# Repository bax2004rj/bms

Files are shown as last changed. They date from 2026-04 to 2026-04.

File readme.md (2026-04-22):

# 3S LIPO battery BMS board
This is a project that allows you to monitor the voltage of a LIPO battery arranged in a 3S configuration. It features auto switch-off by way of MOSFETs, some current monitoring capabilities, and communication with a computer using a UART. This project was designed for use with a [GooseBot](https://github.com/lznfjv/goose). The system is controlled using an Arduino Nano.
## Features
- State of Charge monitoring
- UART/Serial computer communication
- Support for current monitoring with current shunt
- Automatic shutoff on dead battery

Watch the demo video [here](https://github.com/bax2004rj/bms/raw/refs/heads/main/demos/bmsDemo.mp4).
## Installation and building
### Building hardware
Replicate the design shown in the schematics in the /pcb/ folder. PCB designs may become available at a later date.
### Building Firmware
#### Windows
- Download the Arduino IDE to help locate your Arduino, using the Board selector menu.
- Find your copy of `avrdude` (you will need this to upload this code to the Arduino). This is typically found as part of the Arduino IDE, usually under the path `C:\Users\<your username>\AppData\Local\Arduino15\packages\arduino\tools\avrdude\8.0.0-arduino1\bin\avrdude.exe`.
- Clone or download this Git repository.
- In terminal, go to the `firmware/` folder where the code was downloaded to, by running the following command:
```powershell
cd <path/to/file>
```
- Run the following command to upload it to the Arduino (bms.c has already been compiled), replacing the `path\to\board` with the location of your copy of `avrdude`, and the `<location of board>` with your Arduino's serial port:
```powershell
C:\path\to\avrdude.exe -c arduino -p m328p -P <location of board> -U flash:w:build/main.hex
```
#### Linux & MacOS
##### Prerequisites
You will need `avr-gcc` and `avrdude` to get this working.
On Ubuntu/Debian, run:
```bash
$ sudo apt install avr-gcc avrdude
```
if you don't have these tools.
##### Build Instructions
- Clone this project off Github:
```bash
$ git clone github.com/bax2004rj/bms
```
- Go to the Firmware folder under where the repo copied to:
```bash
$ cd ~/bms/firmware
```
- Provided you are not running the other demos found in `/firmware/` the code (`bms.c`) should already be built, and ready to upload to the Arduino. Plug in your Arduino, and locate it using:
```bash
$ ls /dev/ | grep tty
```
- For most Arduinos, the USB connection is typically located at `/dev/ttyACM*` where `*` is the device number. Some Nano boards, such as those used in testing with the CH340 serial driver are located at `/dev/ttyUSB*`.
>[!NOTE]
>You can also use the Arduino IDE for this task as well.

- Run the following command to upload the firmware to the board:
```bash
$ avrdude -c arduino -p m328p -P <location of board> -U flash:w:build/main.hex
```
>[!TIP]
>To compile the demos or recompile the main code (bms.c), use the following command:
>```bash
>$ avr-gcc <filename.c> -o build/main -mmcu=atmega328p -O1 $flags
>```
>Then rerun the avrdude command to upload it to the board.

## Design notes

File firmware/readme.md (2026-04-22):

# Firmware code for BMS
This directory contains the source code and binaries for the Arduino used on the BMS project. There are some demos used during development to test the included header files. These can be compiled and put on the Arduino.
These files are as follows:
- `7sd_trail0test.c`: Simple program that cycles through various numbers that may show up incorrectly on the seven segment display if `7sd.h`'s leading zero detection is faulty.
- `7sd_counttest.c`: Counts from 0-200 using the seven segment display.
- `7sd_uart_counttest`: Version of `7sd_counttest.c` that prints the expected number over the serial port.
- `bms_uart+.c`: Version of `bms.c` that contains a failed, but more advanced serial interaction system. Not recommended to evaluate the hardware.

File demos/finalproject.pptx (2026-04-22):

## Goosebot BMS Board

Richard Carter
4/21/2026

## Introduction

- Battery Management systems are used to control power delivered by battery-powered devices
- Goosebots do not presently have such circuitry
- The design shown here aims to provide this circuit.

## Materials

Item | Quantity
Arduino Nano | 1
Buck Converter | 1
MOSFET (IRF3205) | 2
7 Segment Display | 1
Opamp (LM358) | 1
Resistor (1Ω) | 1
Resistors (220Ω) | 3
Resistor (1KΩ) | 1
Resistor (2KΩ) | 1

## Design

- Design powered by Arduino Nano
- Voltage measured by voltage divider
- 7 segment display to communicate state of charge

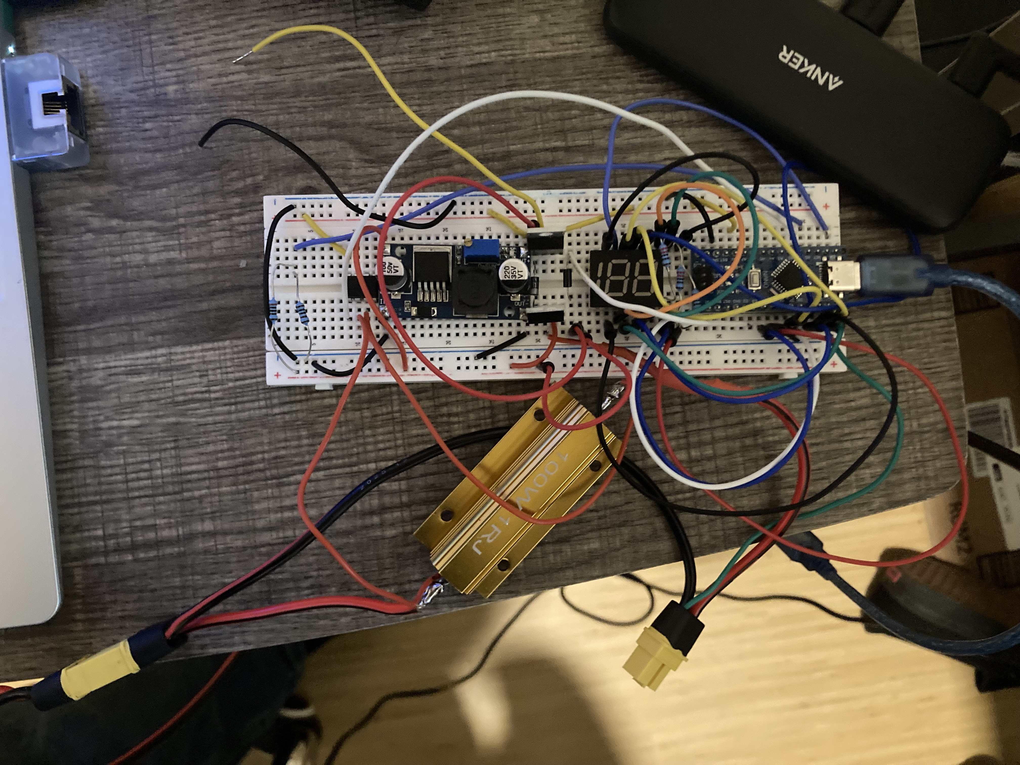
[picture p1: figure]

## Testing Method

- To simulate batteries, a DC supply was connected to the input
  - Testing on actual Goosebots could not be done in time
- Voltage was varied from 13V to 9V
- Switching behavior, state of charge display and Arduino serial ports were monitored.

## Testing

Input Voltage (V) | Arduino Reported Voltage (V) | Reported State of Charge (%)
9.95 | 9.60 | 0
11.6 | 11.2 | 49
13.0 | 13.13 | 100

- Core functionality (voltage measurement) worked largely as expected
- Automatic shut-off did not work, MOSFETS were not properly switched.
- Future iterations may need a MOSFET gate driver.

State Of Charge vs. Voltage

Input Voltage (V) | Output Voltage (V) | Arduino pin voltage (V)
11.5 | 7.936 | 4.835
9.88 | 8.339 | 0.98

Automatic shut-off behavior

## Conclusion

- Voltage monitoring and computer communication was successfully achieved
- Some elements were not functional
  - Current monitoring not fully built in software
  - Battery shutoff functionality was not working

## Thank you!

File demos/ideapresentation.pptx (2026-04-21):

## Goosebot BMS Board Idea

Richard Carter
EEL4312, 4/15/2026

## Design requirements

- 7-Segment display battery level indicator
- Automatic shutoff when battery voltage too low
- UART connection with SBC for communication
- Built in buck converter to run SBC

## Materials and method

- Powered by Arduino Nano
- Sense current using current shunt and voltage divider to measure voltage
- MOSFETs used to switch 12V and 5V rails off

Arduino Nano

D3-13

TX&RX

Display

SBC UART

A0

D2

5V

Buck
converter

Battery

Op-amp

Current Shunt

Gate

5V shut off

5V

Outputs

12V
MOSFET
shut-off

12V

Circuit Block Diagram

## Materials and Method, continued (BOM)

Item | Quantity
Arduino Nano | 1
Buck Converter | 1
MOSFET (IRF3205) | 2
7 Segment Display | 1
Opamp (LM358) | 1
Resistor (1Ω) | 1
Resistors (220Ω) | 3
Resistors (Values TBD) | 2

## Testing Method

- The circuit will be tested on a Goosebot
- The battery will go from fully charged to dead
  - Demonstrates automatic shut-off behavior
- UART communications will be tested during this time

## Timeline

4/9/26
Specifications and
design ideation

4/15/26
Completion of
firware design

4/16/26
Design testing

4/13/26
Parts ordering

4/15/26
Prototype
circuit construction

4/20/26
Finished Product

## Thank you!

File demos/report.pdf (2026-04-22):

## Goosebot Battery Controller

Richard Carter

The software, design, and related materials shown here is available on Github at https://github.com/bax2004rj/bms

## Abstract

Failures due to battery voltage loss on Goosebots have been a major issue, as these robots have no way to measure battery voltage while running. A device to monitor voltages and provide a communication vector and automatic shutoff device are discussed.

## Introduction

On many battery-powered electronic devices, battery management systems are used to control the power delivered to the device [2]. These systems monitor battery voltage to display state of charge, and often have protection circuitry built in to protect the batteries or the device from being damaged. In the case of this situation, Goosebots presently have no such circuitry, and suffer from numerous issues caused by critically low battery voltage. In this report, a circuit is built and demonstrated which aims to resolve these issues.

## Materials and Method

Materials
The materials used are as follows:
Item | Quantity
Arduino Nano | 1
Buck Converter | 1
MOSFET (IRF3205) | 2
7 Segment Display (E30401) | 1
Opamp (LM358) | 1
Resistor (1Ω) | 1
Resistors (220Ω) | 3
Resistor (1KΩ) | 1
Resistor (2KΩ | 1
Table 1. Bill Of Materials

1

Design
The design was built to monitor the voltage using a voltage divider, monitor current by way of a current shunt (which was not fully realized in software), act as a step down for the on-board computer, communicate with the on-board computer, and feature automatic switching [1]. The design of the controller followed the following block diagram:

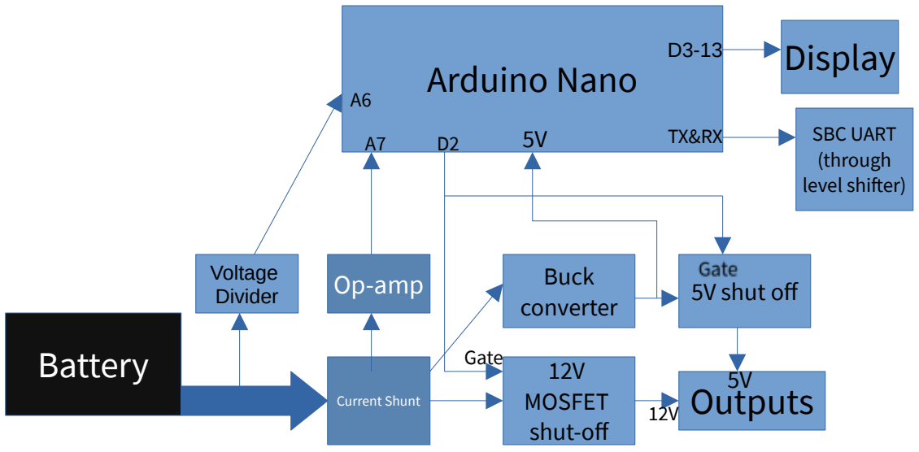
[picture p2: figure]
Arduino Nano; Battery; Current Shunt; Op-amp; 12V MOSFET shut-off; Buck converter; 5V shut off; Outputs; Display; SBC UART (through level shifter); Gate; Voltage Divider

Figure 1. Circuit Block Diagram

2

Using KiCad, the design was made into the following schematic:

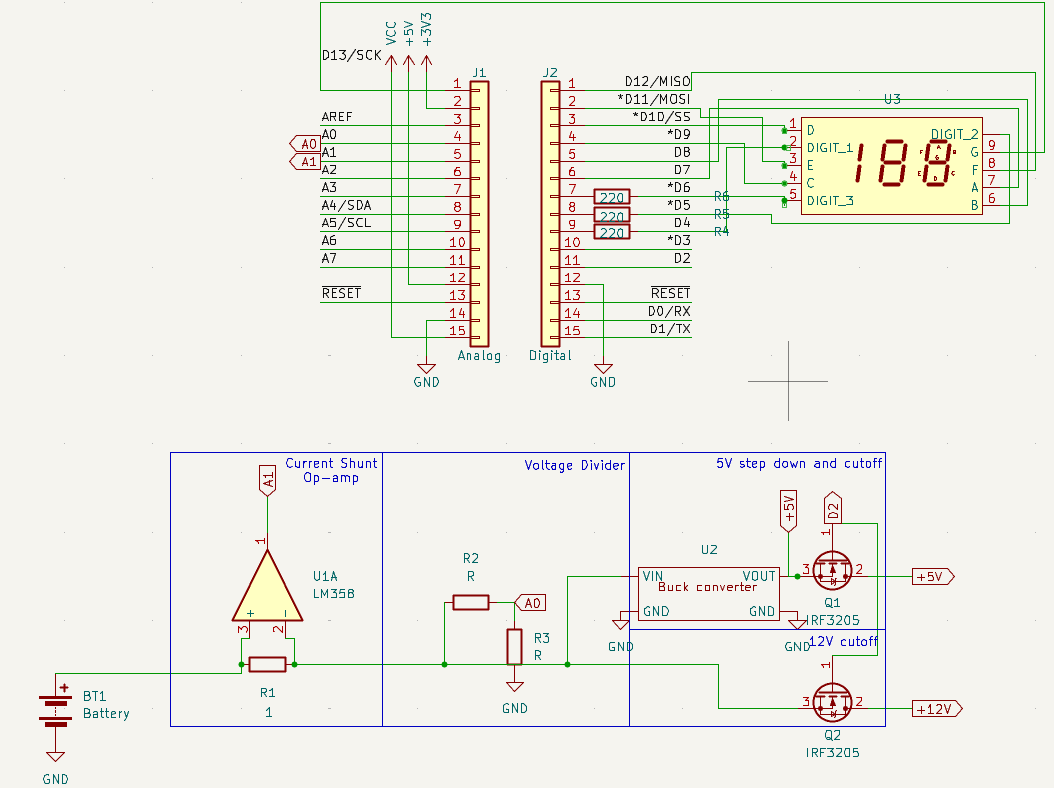
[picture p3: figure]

Figure 2. Circuit Schematic This design was then constructed on a breadboard.

3

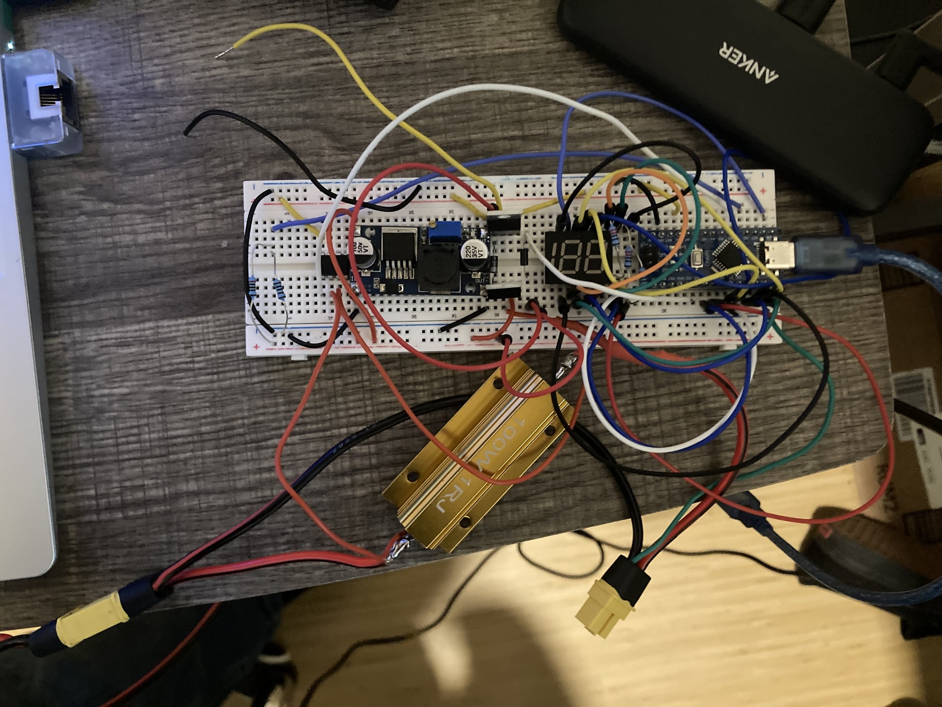
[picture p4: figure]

Figure 3. Breadboard Circuit Testing
Since testing on an actual Goosebot could not be done in time, the behavior of a LiPo battery was simulated using a DC power supply. The voltage was varied from 10V to 13V and the measured voltage and state of charge were noted from the serial communication functionality. This data was obtained over serial via a computer running the Arduino IDE.
To test the low-battery switching functionality, the 12V output was probed with a multimeter and the voltage was varied between just below the 10V (0% state of charge [3]) threshold, and above the 10V threshold. This test was repeated probing the voltage at the output from the Arduino.
Other functionality, such as the current monitoring could not be tested, as the firmware did not have the capability to successfully measure current at the time of testing.

4

## Results

Voltage and state of charge
The voltage results were recorded from the multimeter and Serial Monitor in the below table.
Input Voltage (V) | Arduino Reported Voltage (V) | Reported State of Charge (%)
9.95 | 9.60 | 0
11.6 | 11.2 | 49
13.0 | 13.13 | 100
Table 2. Battery Voltage vs. Reported Voltage vs. State of Charge Switching Circuit
The automatic low battery switching was tested, and the voltage measurements were recorded into the following table.
Input Voltage (V) | Output Voltage (V) | Arduino pin voltage (V)
11.5 | 7.936 | 4.835
9.88 | 8.339 | 0.98
Table 3. Switching Voltage test results

## Discussion

Based on the results of Table 2, the Arduino was able to correctly read out the state of charge of the battery. The voltage measured was approximately off by 0.3-0.5V in the tests shown here, which did affect the state of charge readings. This may affect the perceived battery life by as much as 1%, as the circuit may report a slightly lower battery voltage than usual. It was also noted on tests not recorded here that the difference between the Arduino voltage and the power supply voltage varied at times. This error can be corrected by averaging voltage measurements. Based on Table 3, it can be concluded that the MOSFET switching function was not functional, holding the voltage high at all times. The Arduino was successfully switching on as needed, however the MOSFET did not get properly driven, leading to the fault. Future designs should be tested using a MOSFET gate driver, to properly switch the MOSFET.

5

## Conclusions

It can be concluded that the demonstrated circuit was able to successfully measure the voltage and state of charge of a LiPo battery, and communicate state of charge with an on-board computer. The switching functionality was not functional, but future circuit implementations could make this system functional.
Overall, the voltage monitoring and computer communication systems were successfully implemented and achieved.

## Acknowledgment

The author would like to thank Dr. Hoan Ngo for the opportunity to work on this project and offering insight on the design of Goosebots. Additionally, the author would also like to thank various friends and colleagues within Dr. Ngo’s Autonomous Robotic Systems course, who offered insight about the design of Goosebots as well the robot’s specifications.

## References

[1] Carter, R. “Goosebot BMS Board Idea”, April 2026.
[2] Husain, I. “Electric and Hybrid Vehicles Design Fundamentals”, 3rd ed. Boca Raton, FL, USA: CRC Press, 2021.
[3] Beech, J. “The care and feeding of LiPo packs”, Promodeler. https://www.promodeler.com/askJohn/How-To-Care-for-LiPo-Packs (accessed April 15, 2026)

6

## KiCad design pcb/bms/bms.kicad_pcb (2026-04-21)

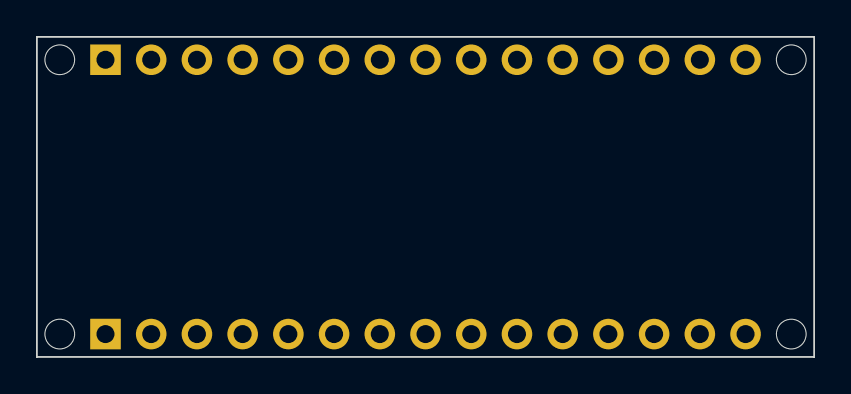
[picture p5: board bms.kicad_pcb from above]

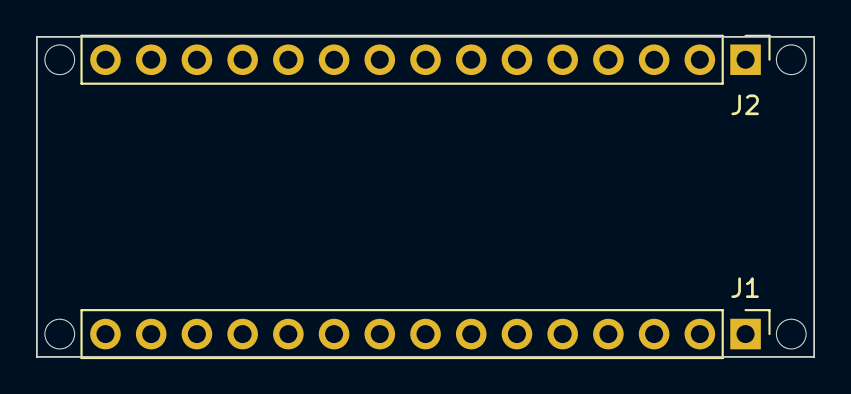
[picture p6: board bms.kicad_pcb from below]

Board: 2 copper layers, 43.2 x 17.8 mm, 6 parts (2 on the bottom side), 2 nets, no tracks yet.

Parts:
J1: Analog; PinHeader_1x15_P2.54mm_Vertical
J2: Digital; PinHeader_1x15_P2.54mm_Vertical
MH1, MH2, MH3, MH4: MountingHole_65mil

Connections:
/~RESET: J1.13, J2.13
GND: J1.14, J2.12

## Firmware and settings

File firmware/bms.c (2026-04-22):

/*
 *  3S Battery management system
 *  Copyright (C) 2026 Richard Carter (bax2004rj)
 *
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
 You should have received a copy of the GNU General Public License
 along with this program.  If not, see <https://www.gnu.org/licenses/>.
 */
#define F_CPU 16000000UL
#include <string.h>
#include <avr/io.h>
#include <avr/interrupt.h>
#include <util/delay.h>
#include "7sd.h"
#include "uart.h"
#include "adc.h"

int percent = 50;
const double maximumVoltage= 12.6;//12.6V = 100% battery for 3S.
const double mininumVoltage= 10.0;//10V = 0% battery for 3S.
const double voltageChange=maximumVoltage-mininumVoltage;
int dataSent = 0;

char cmd[32];
int cmdChars = 0;
int cmdStatus = 0x03;//bit 0: command ready, bit 1: ready indicator generated, bit 2: newline sent, bit 3: echo off, bit 4: power off, bit 5: monitor loop enabled
int dispMode = 0;//0: percentage (default), 1: voltage, 2+ off

int main(){
    init7sd();
    initADC();
    initUart();
    DDRD |= (1<<3); //MOSFET pin
    while(1){
        //Check battery voltage
        int adcVal = analogRead(0);
        float voltage = ((double)adcVal/1023)*15.84;
        if(voltage<maximumVoltage&&voltage>mininumVoltage){
            double p = ((voltage-mininumVoltage)/voltageChange)*100;
            percent = (int) p;
        } else if (voltage<=mininumVoltage){
            percent = 0;
        } else {
            percent = 100;
        }
        if(dispMode==0){
            setNumericalValue(percent);
        } else if(dispMode==1){
            setNumericalValue(voltage);
        }
        if(percent == 1&&dataSent==0){ //Send shutdown request over UART before battery dies
            printf("\n\rshutdown\n\r");
            dataSent = 1;
        }
        if((percent <= 0||cmdStatus&(1<<4))==!0){ //0% or command shutoff
            PORTD &= ~(1<<3);
        }else{
            PORTD |= (1<<3);
        }
        //Current monitoring
        int currentADC=analogRead(1);
        //UART printing
        printf("ADC: %d, Voltage: %f, Battery Percentage: %d, ADC1 (Current):%d \n\r",adcVal,voltage,percent,currentADC);
    }
    return 0;
}
ISR(TIMER0_OVF_vect){
    updateDigits();
}

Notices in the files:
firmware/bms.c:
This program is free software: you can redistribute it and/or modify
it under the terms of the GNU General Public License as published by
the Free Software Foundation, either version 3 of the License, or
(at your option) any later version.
